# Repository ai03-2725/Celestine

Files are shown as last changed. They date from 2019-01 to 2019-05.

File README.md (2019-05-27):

# Celestine
A Hi-Tek 725 TKL PCB

#### In light of recent claims that I am 100% liable for any of my open source PCBs, I am adding this disclaimer.
#### I provide these PCBs as a reference for designing keyboard PCBs. Using them within your projects will require a will to do research of one's own and to learn the workings of them, potentially fixing issues if they exist.
# I provide these PCBs without liability and without any guarantees regarding functionality, as expressed in the MIT license under which all of these PCBs are licensed.

This project aims to revive the use of NMB/Hi-Tek 725 series switches, commonly known as "Space Invaders".

Massive credits go to Engicoder, mcmaxmcmc, and many others for helping me along the way with measurements of existing boards and switches.

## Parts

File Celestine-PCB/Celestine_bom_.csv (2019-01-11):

Component | Description | Part | References | Value | Footprint | Quantity Per PCB
1 | Capacitor | C_Small | C3 C4 C5 | 0.1uF | C_0603 | 3
2 | Capacitor | C_Small | C2 | 10uF | C_0603 | 1
3 | Capacitor | C_Small | C6 | 1uF | C_0603 | 1
4 | Capacitor | C_Small | C7 C8 | 22pF | C_0603 | 2
5 | Diode, Generic | D_Small | D1 D2 D3 D4 D5 D6 D7 D8 D9 D10 D11 D12 D13 D14 D15 D16 D17 D18 D19 D20 D21 D22 D23 D24 D25 D26 D27 D28 D29 D30 D31 D32 D33 D34 D35 D36 D37 D38 D39 D40 D41 D42 D43 D45 D46 D47 D48 D49 D50 D51 D52 D53 D54 D55 D56 D58 D59 D60 D61 D62 D63 D64 D65 D66 D67 D68 D69 D70 D71 D72 D73 D74 D75 D76 D77 D78 D79 D80 D81 D82 D83 D84 D85 D86 D87 D88 D89 | SOD-123 | D_SOD-123 | 87
6 | Polyfuse, 500mA hold, 1A trip | Polyfuse_Small | F1 | 500mA | Fuse_SMD1206_Reflow | 1
7 | Resistor | R_Small | R70 | 10k | R_0805 | 1
8 | Resistor | R_Small | R71 | 1k | R_0805 | 1
9 | Resistor | R_Small | R67 R68 | 22 | R_0805 | 2
10 | Resistor | R_Small | R73 R74 | 5.1k | R_0805 | 2
11 | Push button, SMT, 5.2 x 5.2mm | SW_Push | SW1 | SW_Push | SKQG-1155865 | 1
12 | Microcontroller, ATmega32u4-AU | ATmega32U4-AU | U1 | ATmega32U4-AU | TQFP-44_10x10mm_Pitch0.8mm | 1
13 | ESD Protection Chip | PRTR5V0U2X | U2 | PRTR5V0U2X | SOT143B | 1
14 | USB Type-C Connector | HRO-TYPE-C-31-M-12 | USB1 | HRO-TYPE-C-31-M-12 | HRO-TYPE-C-31-M-12-Assembly | 1
15 | Crystal, SMT, 3.2 x 2.5mm, 4 pads | Crystal_GND24 | Y1 | 16Mhz | Crystal_SMD_3225-4pin_3.2x2.5mm | 1
Component Groups: | 15
Component Count: | 106
Fitted Components: | 106
Number of PCBs: | 1
Total components: | 106
Schematic Version:
Schematic Date:
BoM Date: | 1/11/2019 0:30
Schematic Source:
KiCad Version: | Eeschema (5.0.0)

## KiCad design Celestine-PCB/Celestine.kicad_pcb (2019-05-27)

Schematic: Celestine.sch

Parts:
C2: 10uF; C_0603
C3, C4, C5: 0.1uF; C_0603
C6: 1uF; C_0603
C7, C8: 22pF; C_0603
D1, D2, D3, D4, D5, D6, D7, D8, D9, D10, D11, D12, D13, D14, D15, D16, D17, D18, D19, D20, D21, D22, D23, D24, D25, D26, D27, D28, D29, D30, D31, D32, D33, D34, D35, D36, D37, D38, D39, D40, D41, D42, D43, D45, D46, D47, D48, D49, D50, D51, D52, D53, D54, D55, D56, D58, D59, D60, D61, D62, D63, D64, D65, D66, D67, D68, D69, D70, D71, D72, D73, D74, D75, D76, D77, D78, D79, D80, D81, D82, D83, D84, D85, D86, D87, D88, D89: SOD-123; D_SOD-123
F1: 500mA; Fuse_SMD1206_Reflow
K_#1, K_#2, K_#3, K_#4, K_#5, K_#6, K_#7, K_#8, K_#9, K_#10: MX-1U; Hitek725-1U
K_'1: MX-1U; Hitek725-1U
K_,1: MX-1U; Hitek725-1U
K_-1: MX-1U; Hitek725-1U
K_.1: MX-1U; Hitek725-1U
K_/1: MX-1U; Hitek725-1U
K_;1: MX-1U; Hitek725-1U
K_=1: MX-1U; Hitek725-1U
K_A1: MX-1U; Hitek725-1U
K_ALT1, K_ALT2: MX-1.5U; Hitek725-1.5U
K_B1: MX-1U; Hitek725-1U
K_BACK1: MX-2U; Hitek725-2U-DudPad
K_C1: MX-1U; Hitek725-1U
K_CAPS1: MX-1.75U; Hitek725-1.75U
K_CTRL1: MX-2U; Hitek725-2U
K_CTRL2: MX-1.5U; Hitek725-1.5U
K_D1: MX-1U; Hitek725-1U
K_DEL1: MX-1U; Hitek725-1U
K_DOWN1: MX-1U; Hitek725-1U
K_E1: MX-1U; Hitek725-1U
K_END1: MX-1U; Hitek725-1U
K_ENTER1: MX-2.25U; Hitek725-2.25U
K_ENTER2: MX-BAE; Hitek725-BigAssEnter-DudPad
K_ESC1: MX-1U; Hitek725-1U
K_F1: MX-1U; Hitek725-1U
K_FN1, K_FN2, K_FN3, K_FN4, K_FN5, K_FN6, K_FN7, K_FN8, K_FN9, K_FN10, K_FN11, K_FN12: MX-1U; Hitek725-1U
K_G1: MX-1U; Hitek725-1U
K_H1: MX-1U; Hitek725-1U
K_HOME1: MX-1U; Hitek725-1U
K_I1: MX-1U; Hitek725-1U
K_INS1: MX-1U; Hitek725-1U
K_J1: MX-1U; Hitek725-1U
K_K1: MX-1U; Hitek725-1U
K_L1: MX-1U; Hitek725-1U
K_LEFT1: MX-1U; Hitek725-1U
K_M1: MX-1U; Hitek725-1U
K_N1: MX-1U; Hitek725-1U
K_O1: MX-1U; Hitek725-1U
K_P1: MX-1U; Hitek725-1U
K_PAUSE1: MX-1U; Hitek725-1U
K_PGDN1: MX-1U; Hitek725-1U
K_PGUP1: MX-1U; Hitek725-1U
K_PRTSC1: MX-1U; Hitek725-1U
K_Q1: MX-1U; Hitek725-1U
K_R1: MX-1U; Hitek725-1U
K_RALT1, K_RALT2: MX-1.5U; Hitek725-1.5U
K_RCTRL1: MX-2U; Hitek725-2U
K_RCTRL2: MX-1.5U; Hitek725-1.5U
K_RIGHT1: MX-1U; Hitek725-1U
K_RSHIFT1: MX-2.75U; Hitek725-2.75U
K_RWIN1: MX-1U; Hitek725-1U
K_S1: MX-1U; Hitek725-1U
K_SBACK1: MX-1U; Hitek725-1U
K_SBACK2: MX-1U; Hitek725-1U-DudPad
K_SHIFT1: MX-2.25U; Hitek725-2.25U
K_SLCK1: MX-1U; Hitek725-1U
K_SPACE1: MX-7U; Hitek725-7U
K_T1: MX-1U; Hitek725-1U
K_TAB1: MX-1.5U; Hitek725-1.5U
K_U1: MX-1U; Hitek725-1U
K_UP1: MX-1U; Hitek725-1U
K_V1: MX-1U; Hitek725-1U
K_W1: MX-1U; Hitek725-1U
K_WIN1: MX-1U; Hitek725-1U
K_X1: MX-1U; Hitek725-1U
K_Y1: MX-1U; Hitek725-1U
K_Z1: MX-1U; Hitek725-1U
K_[1: MX-1U; Hitek725-1U
K_\1: MX-1.5U; Hitek725-1.5U
K_]1: MX-1U; Hitek725-1U
K_`1: MX-1U; Hitek725-1U
R67, R68: 22; R_0805
R70: 10k; R_0805
R71: 1k; R_0805
R73, R74: 5.1k; R_0805
SW1: SW_Push; SKQG-1155865
U1: ATmega32U4-AU; TQFP-44_10x10mm_Pitch0.8mm
U2: PRTR5V0U2X; SOT143B
USB1: HRO-TYPE-C-31-M-12; HRO-TYPE-C-31-M-12-Assembly
Y1: 16Mhz; Crystal_SMD_3225-4pin_3.2x2.5mm

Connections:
COL0: K_CAPS1.1, K_CTRL1.1, K_CTRL2.2, K_ESC1.1, K_SHIFT1.1, K_TAB1.1, K_`1.1, U1.26 (PD6)
COL1: K_#1.1, K_A1.1, K_Q1.1, K_WIN1.1, U1.27 (PD7)
COL2: K_#2.1, K_ALT1.1, K_ALT2.2, K_FN1.1, K_S1.1, K_W1.1, K_Z1.1, U1.28 (PB4)
COL3: K_#3.1, K_D1.1, K_E1.1, K_FN2.1, K_X1.1, U1.29 (PB5)
COL4: K_#4.1, K_C1.1, K_F1.1, K_FN3.1, K_R1.1, U1.30 (PB6)
COL5: K_#5.1, K_FN4.1, K_G1.1, K_T1.1, K_V1.1, U1.31 (PC6)
COL6: K_#6.1, K_B1.1, K_FN5.1, K_H1.1, K_Y1.1, U1.32 (PC7)
COL7: K_#7.1, K_FN6.1, K_J1.1, K_N1.1, K_SPACE1.1, K_U1.1, U1.36 (PF7)
COL8: K_#8.1, K_FN7.1, K_I1.1, K_K1.1, K_M1.1, U1.37 (PF6)
COL9: K_#9.1, K_,1.1, K_FN8.1, K_L1.1, K_O1.1, U1.38 (PF5)
COL10: K_#10.1, K_.1.1, K_;1.1, K_FN9.1, K_P1.1, U1.39 (PF4)
COL11: K_'1.1, K_-1.1, K_/1.1, K_FN10.1, K_RALT1.1, K_RALT2.2, K_[1.1, U1.40 (PF1)
COL12: K_=1.1, K_FN11.1, K_RSHIFT1.1, K_RWIN1.1, K_]1.1, U1.41 (PF0)
COL13: K_BACK1.2, K_ENTER1.1, K_ENTER2.2, K_FN12.1, K_RCTRL1.1, K_RCTRL2.2, K_SBACK1.1, K_SBACK2.1, K_\1.1, U1.25 (PD4)
COL14: K_DEL1.1, K_INS1.1, K_LEFT1.1, K_PRTSC1.1, U1.22 (PD5)
COL15: K_DOWN1.1, K_END1.1, K_HOME1.1, K_SLCK1.1, K_UP1.1, U1.21 (PD3)
COL16: K_PAUSE1.1, K_PGDN1.1, K_PGUP1.1, K_RIGHT1.1, U1.20 (PD2)
D+: R68.1, U1.4 (D+)
D-: R67.1, U1.3 (D-)
GND: C2.1, C3.1, C4.1, C5.1, C6.2, C7.2, C8.2, R71.1, R73.1, R74.1, SW1.1, U1.5 (UGND), U1.15 (GND), U1.23 (GND), U1.35 (GND), U1.43 (GND), U2.1, USB1.1, USB1.12, USB1.13, Y1.2, Y1.4
unnamed: C6.1, U1.6 (UCAP)
unnamed: C7.1, U1.17 (XTAL1), Y1.1
unnamed: C8.1, U1.16 (XTAL2), Y1.3
unnamed: D1.2, K_`1.2
unnamed: D2.2, K_#1.2
unnamed: D3.2, K_#2.2
unnamed: D4.2, K_#3.2
unnamed: D5.2, K_#4.2
unnamed: D6.2, K_#5.2
unnamed: D7.2, K_#6.2
unnamed: D8.2, K_#7.2
unnamed: D9.2, K_#8.2
unnamed: D10.2, K_#9.2
unnamed: D11.2, K_#10.2
unnamed: D12.2, K_-1.2
unnamed: D13.2, K_=1.2
unnamed: D14.2, K_BACK1.1, K_SBACK1.2
unnamed: D15.2, K_ESC1.2
unnamed: D16.2, K_TAB1.2
unnamed: D17.2, K_Q1.2
unnamed: D18.2, K_W1.2
unnamed: D19.2, K_E1.2
unnamed: D20.2, K_R1.2
unnamed: D21.2, K_T1.2
unnamed: D22.2, K_Y1.2
unnamed: D23.2, K_U1.2
unnamed: D24.2, K_I1.2
unnamed: D25.2, K_O1.2
unnamed: D26.2, K_P1.2
unnamed: D27.2, K_[1.2
unnamed: D28.2, K_]1.2
unnamed: D29.2, K_\1.2
unnamed: D30.2, K_FN1.2
unnamed: D31.2, K_CAPS1.2
unnamed: D32.2, K_A1.2
unnamed: D33.2, K_S1.2
unnamed: D34.2, K_D1.2
unnamed: D35.2, K_F1.2
unnamed: D36.2, K_G1.2
unnamed: D37.2, K_H1.2
unnamed: D38.2, K_J1.2
unnamed: D39.2, K_K1.2
unnamed: D40.2, K_L1.2
unnamed: D41.2, K_;1.2
unnamed: D42.2, K_'1.2
unnamed: D43.2, K_ENTER1.2
unnamed: D45.2, K_SHIFT1.2
unnamed: D46.2, K_Z1.2
unnamed: D47.2, K_X1.2
unnamed: D48.2, K_C1.2
unnamed: D49.2, K_V1.2
unnamed: D50.2, K_B1.2
unnamed: D51.2, K_N1.2
unnamed: D52.2, K_M1.2
unnamed: D53.2, K_,1.2
unnamed: D54.2, K_.1.2
unnamed: D55.2, K_/1.2
unnamed: D56.2, K_RSHIFT1.2
unnamed: D58.2, K_FN2.2
unnamed: D59.2, K_CTRL1.2, K_CTRL2.1
unnamed: D60.2, K_FN3.2
unnamed: D61.2, K_SPACE1.2
unnamed: D62.2, K_FN4.2
unnamed: D63.2, K_FN5.2
unnamed: D64.2, K_RALT1.2, K_RALT2.1
unnamed: D65.2, K_RCTRL1.2, K_RCTRL2.1
unnamed: D66.2, K_FN6.2
unnamed: D67.2, K_ALT1.2, K_ALT2.1
unnamed: D68.2, K_SBACK2.2
unnamed: D69.2, K_FN7.2
unnamed: D70.2, K_FN8.2
unnamed: D71.2, K_FN9.2
unnamed: D72.2, K_FN10.2
unnamed: D73.2, K_FN11.2
unnamed: D74.2, K_FN12.2
unnamed: D75.2, K_WIN1.2
unnamed: D76.2, K_RWIN1.2
unnamed: D77.2, K_PRTSC1.2
unnamed: D78.2, K_SLCK1.2
unnamed: D79.2, K_PAUSE1.2
unnamed: D80.2, K_INS1.2
unnamed: D81.2, K_HOME1.2
unnamed: D82.2, K_PGUP1.2
unnamed: D83.2, K_DEL1.2
unnamed: D84.2, K_END1.2
unnamed: D85.2, K_PGDN1.2
unnamed: D86.2, K_UP1.2
unnamed: D87.2, K_LEFT1.2
unnamed: D88.2, K_DOWN1.2
unnamed: D89.2, K_RIGHT1.2
unnamed: R67.2, U2.3, USB1.5, USB1.7
unnamed: R68.2, U2.2, USB1.6, USB1.8
unnamed: R70.2, SW1.2, U1.13 (~RESET)
unnamed: R71.2, U1.33 (~HWB~/PE2)
unnamed: R73.2, USB1.4
unnamed: R74.2, USB1.10
ROW0: D15.1, D30.1, D58.1, D60.1, D62.1, D63.1, D66.1, D69.1, D70.1, D71.1, D72.1, D73.1, D74.1, D77.1, D78.1, D79.1, U1.9 (PB1)
ROW1: D1.1, D2.1, D3.1, D4.1, D5.1, D6.1, D7.1, D8.1, D9.1, D10.1, D11.1, D12.1, D13.1, D14.1, D80.1, D81.1, D82.1, U1.10 (PB2)
ROW2: D16.1, D17.1, D18.1, D19.1, D20.1, D21.1, D22.1, D23.1, D24.1, D25.1, D26.1, D27.1, D28.1, D29.1, D83.1, D84.1, D85.1, U1.11 (PB3)
ROW3: D31.1, D32.1, D33.1, D34.1, D35.1, D36.1, D37.1, D38.1, D39.1, D40.1, D41.1, D42.1, D43.1, U1.12 (PB7)
ROW4: D45.1, D46.1, D47.1, D48.1, D49.1, D50.1, D51.1, D52.1, D53.1, D54.1, D55.1, D56.1, D68.1, D86.1, U1.18 (PD0)
ROW5: D59.1, D61.1, D64.1, D65.1, D67.1, D75.1, D76.1, D87.1, D88.1, D89.1, U1.19 (PD1)
VCC: F1.2, U2.4, USB1.2, USB1.11

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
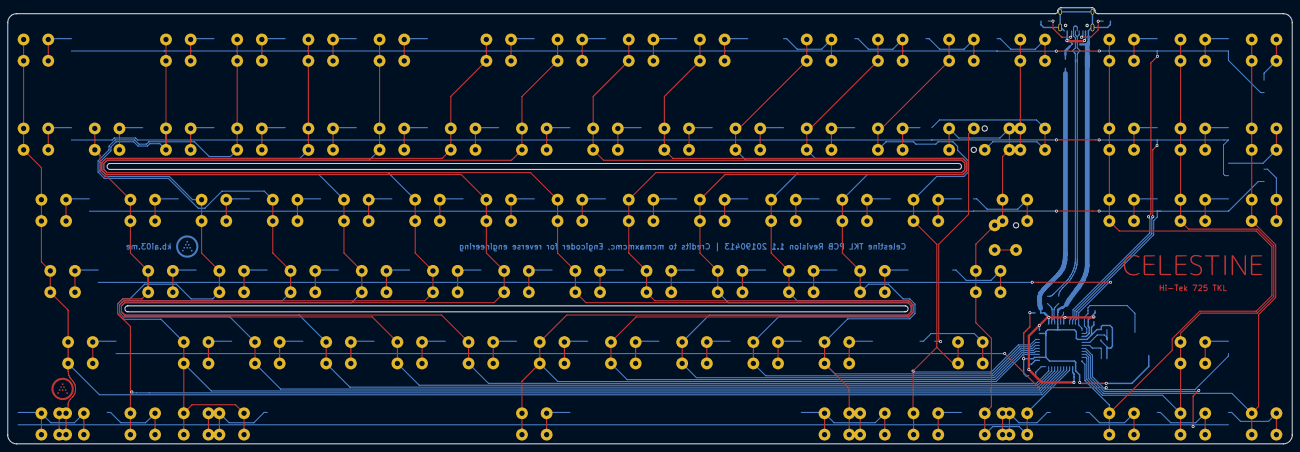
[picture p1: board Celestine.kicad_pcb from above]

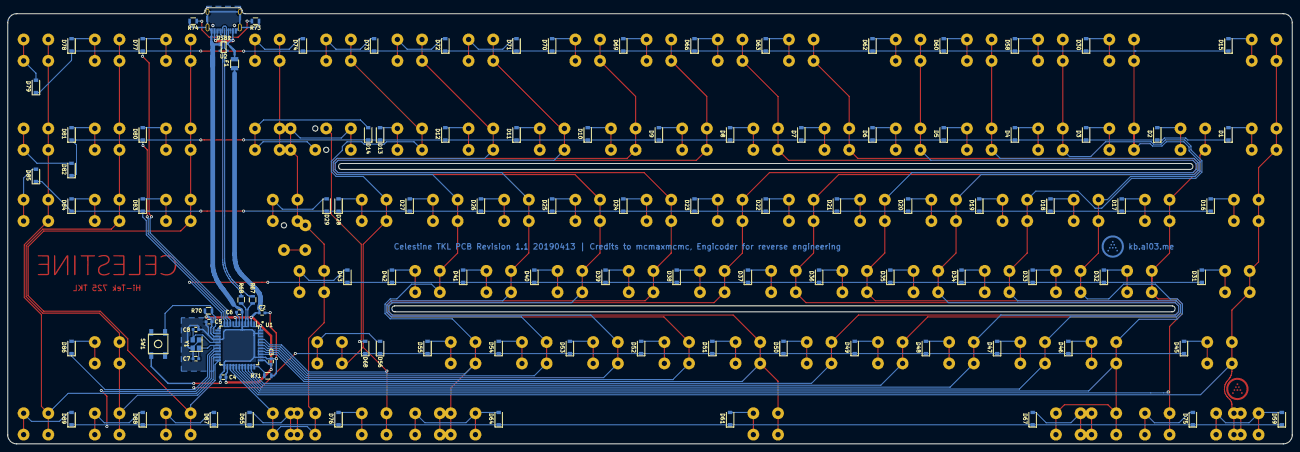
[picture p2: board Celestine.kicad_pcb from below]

Board: 2 copper layers, 343.7 x 116.7 mm, 199 parts (106 on the bottom side), 124 nets.

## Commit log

2019-01-07 Add submodules, make footprint
    [Celestine.kicad_pcb, Celestine.sch]
2019-01-09 Begin add libraries
    [Celestine.sch]
2019-01-09 Add footprint libs
2019-01-09 Bind some footprints
    [Celestine.sch]
2019-01-09 New footprint data by Engicoder
2019-01-09 Make a few sizes of the footprint
2019-01-09 Build generic schematic
    [Celestine.sch]
2019-01-10 Build the PCB
    [Celestine.sch]
2019-01-11 Remove need for jumpers
    [Celestine.kicad_pcb, Celestine.sch]
2019-01-11 Generate production data
    [Celestine-B.Cu.gbl, Celestine-B.Mask.gbs, Celestine-B.SilkS.gbo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]
2019-01-11 Clean BOM
    [Celestine_bom_.csv]
2019-01-11 Generate sandwich case
    [Celestine-SandwichCase-Bottom-B.Cu.gbl, Celestine-SandwichCase-Bottom-B.Mask.gbs, Celestine-SandwichCase-Bottom-B.SilkS.gbo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]
2019-01-11 Rename gerbers
